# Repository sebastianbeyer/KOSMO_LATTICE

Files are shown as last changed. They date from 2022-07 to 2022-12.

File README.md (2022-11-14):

## KOSMO format adoption from Mutable Instruments Grids

Using the Schematic of Mutable Instruments and initial Kicad files by www.quinie.nl

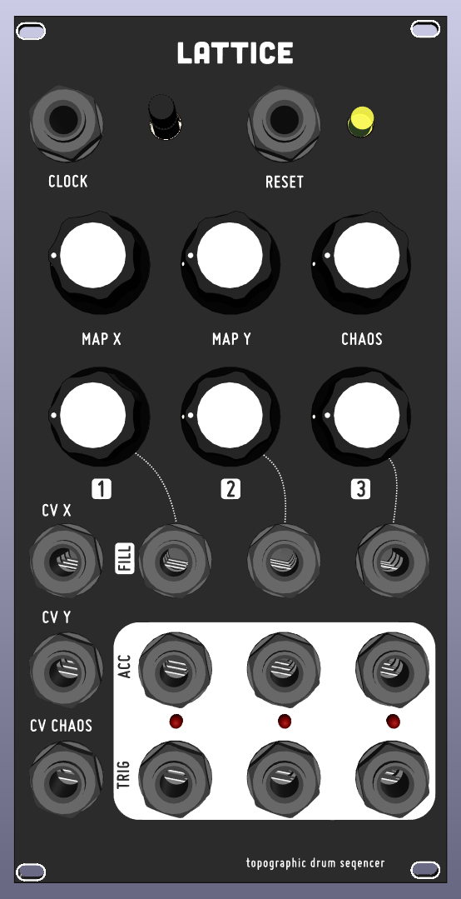
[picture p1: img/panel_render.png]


I had to fix the pot direction and the button but now it works!
Remember to adjust the LED resistors (`R37, R38, R39`) to the LEDs your are using!
For the firmware I have added the compiled firmware (`grids.hex`) and a script on how to upload it to your nano (`upload.sh`, you need to adjust the paths)

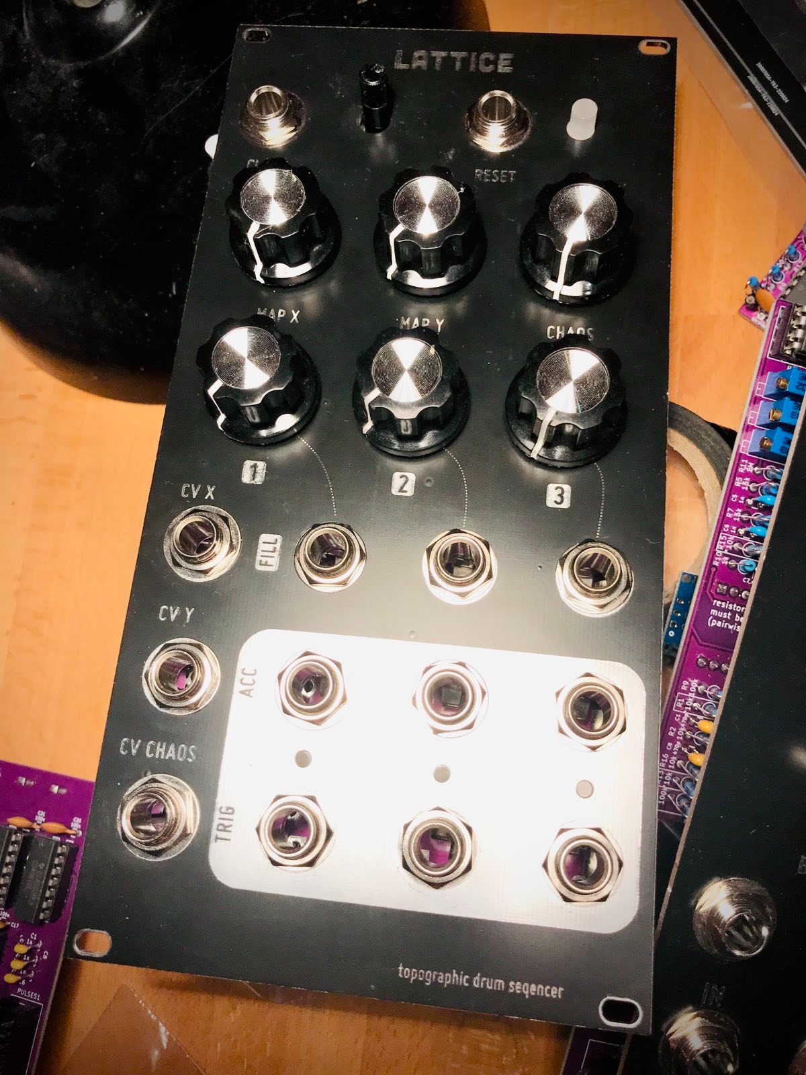
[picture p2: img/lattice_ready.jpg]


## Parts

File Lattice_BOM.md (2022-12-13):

# Lattice.kicad_sch BOM

Tue 13 Dec 2022 10:29:21 CET

Generated from schematic by Eeschema 6.0.8-f2edbf62ab~116~ubuntu22.04.1

**Component Count:** 107

| Refs | Qty | Component | Description | Vendor | SKU |
| ----- | --- | ---- | --- | ---- | ---- |
| A1 | 1 | Arduino_Nano_v2.x |  |  |  |
| C1, C2, C3, C4, C5, C6, C16 | 7 | 10nf |  |  |  |
| C7, C8, C10, C11, C12 | 5 | 100nf |  |  |  |
| C9, C14 | 2 | 10uf |  |  |  |
| C13, C15 | 2 | 0.47uf |  |  |  |
| CH1 | 1 | CH1 | Audio Jack, 2 Poles (Mono / TS), Switched T Pole (Normalling) | Tayda | A-1121 |
| CH1_AC1 | 1 | CH1_ACC | Audio Jack, 2 Poles (Mono / TS), Switched T Pole (Normalling) | Tayda | A-1121 |
| CH1_FILL1 | 1 | CV_CH1 | Audio Jack, 2 Poles (Mono / TS), Switched T Pole (Normalling) | Tayda | A-1121 |
| CH2 | 1 | CH2 | Audio Jack, 2 Poles (Mono / TS), Switched T Pole (Normalling) | Tayda | A-1121 |
| CH2_AC1 | 1 | CH2_ACC | Audio Jack, 2 Poles (Mono / TS), Switched T Pole (Normalling) | Tayda | A-1121 |
| CH2_FILL1 | 1 | CV_CH2 | Audio Jack, 2 Poles (Mono / TS), Switched T Pole (Normalling) | Tayda | A-1121 |
| CH3 | 1 | CH3 | Audio Jack, 2 Poles (Mono / TS), Switched T Pole (Normalling) | Tayda | A-1121 |
| CH3_AC1 | 1 | CH3_ACC | Audio Jack, 2 Poles (Mono / TS), Switched T Pole (Normalling) | Tayda | A-1121 |
| CH3_FILL1 | 1 | CV_CH3 | Audio Jack, 2 Poles (Mono / TS), Switched T Pole (Normalling) | Tayda | A-1121 |
| CLOCK1 | 1 | CV_CLOCK | Audio Jack, 2 Poles (Mono / TS), Switched T Pole (Normalling) | Tayda | A-1121 |
| D1, D5 | 2 | 1N4148 | Standard switching diode, DO-35 | Tayda | A-157 |
| D2 | 1 | CH1 | Light emitting diode |  |  |
| D3 | 1 | CH2 |  |  |  |
| D4 | 1 | CH3 |  |  |  |
| D6, D7 | 2 | 1N5817 | Schottky Barrier Rectifier Diode, DO-41 | Tayda | A-159 |
| H1, H2 | 2 | MountingHole |  |  |  |
| J1, J3 | 2 | Conn_01x10_Male | Generic connector, single row, 01x10, script generated (kicad-library-utils/schlib/autogen/connector/) |  |  |
| J2, J4 | 2 | Conn_01x10_Female | Generic connector, single row, 01x10, script generated (kicad-library-utils/schlib/autogen/connector/) |  |  |
| J5 | 1 | clock_out | KK254 Molex header | Tayda | A-804 |
| J6 | 1 | any trig | KK254 Molex header | Tayda | A-804 |
| J7 | 1 | midi in | KK254 Molex header | Tayda | A-805 |
| J8 | 1 | Synth_power_2x5 | Pin header 2.54 mm 2x5 | Tayda | A-2939 |
| P_CH1, P_CH2, P_CH3, P_RND1, P_TEMPO1, P_X1, P_Y1 | 7 | 10k |  |  |  |
| Q1, Q2 | 2 | 2N3904 |  |  |  |
| R1 | 1 | 2k |  |  |  |
| R2, R3, R4, R5, R6, R7, R8, R9, R10, R11, R12, R13, R16, R17, R19, R20, R21, R22, R23, R25, R26, R27, R28, R29, R34, R35, R36, R40, R41, R42 | 30 | 100k |  |  |  |
| R14, R15, R18, R24, R30, R31, R32, R33 | 8 | 1k |  |  |  |
| R37, R38, R39 | 3 | 2.2k |  |  |  |
| R43 | 1 | 10k |  |  |  |
| RESET1 | 1 | CV_RESET | Audio Jack, 2 Poles (Mono / TS), Switched T Pole (Normalling) | Tayda | A-1121 |
| RND1 | 1 | CV_RND | Audio Jack, 2 Poles (Mono / TS), Switched T Pole (Normalling) | Tayda | A-1121 |
| SW1 | 1 | PB6149-L-s |  |  |  |
| U1, U2, U3 | 3 | MCP6002_1 |  |  |  |
| U4 | 1 | 74HC595 |  |  |  |
| U5 | 1 | L7805 |  |  |  |
| U6 | 1 | LM4040LP-5 |  |  |  |
| X1 | 1 | CV_X | Audio Jack, 2 Poles (Mono / TS), Switched T Pole (Normalling) | Tayda | A-1121 |
| Y1 | 1 | CV_Y | Audio Jack, 2 Poles (Mono / TS), Switched T Pole (Normalling) | Tayda | A-1121 |

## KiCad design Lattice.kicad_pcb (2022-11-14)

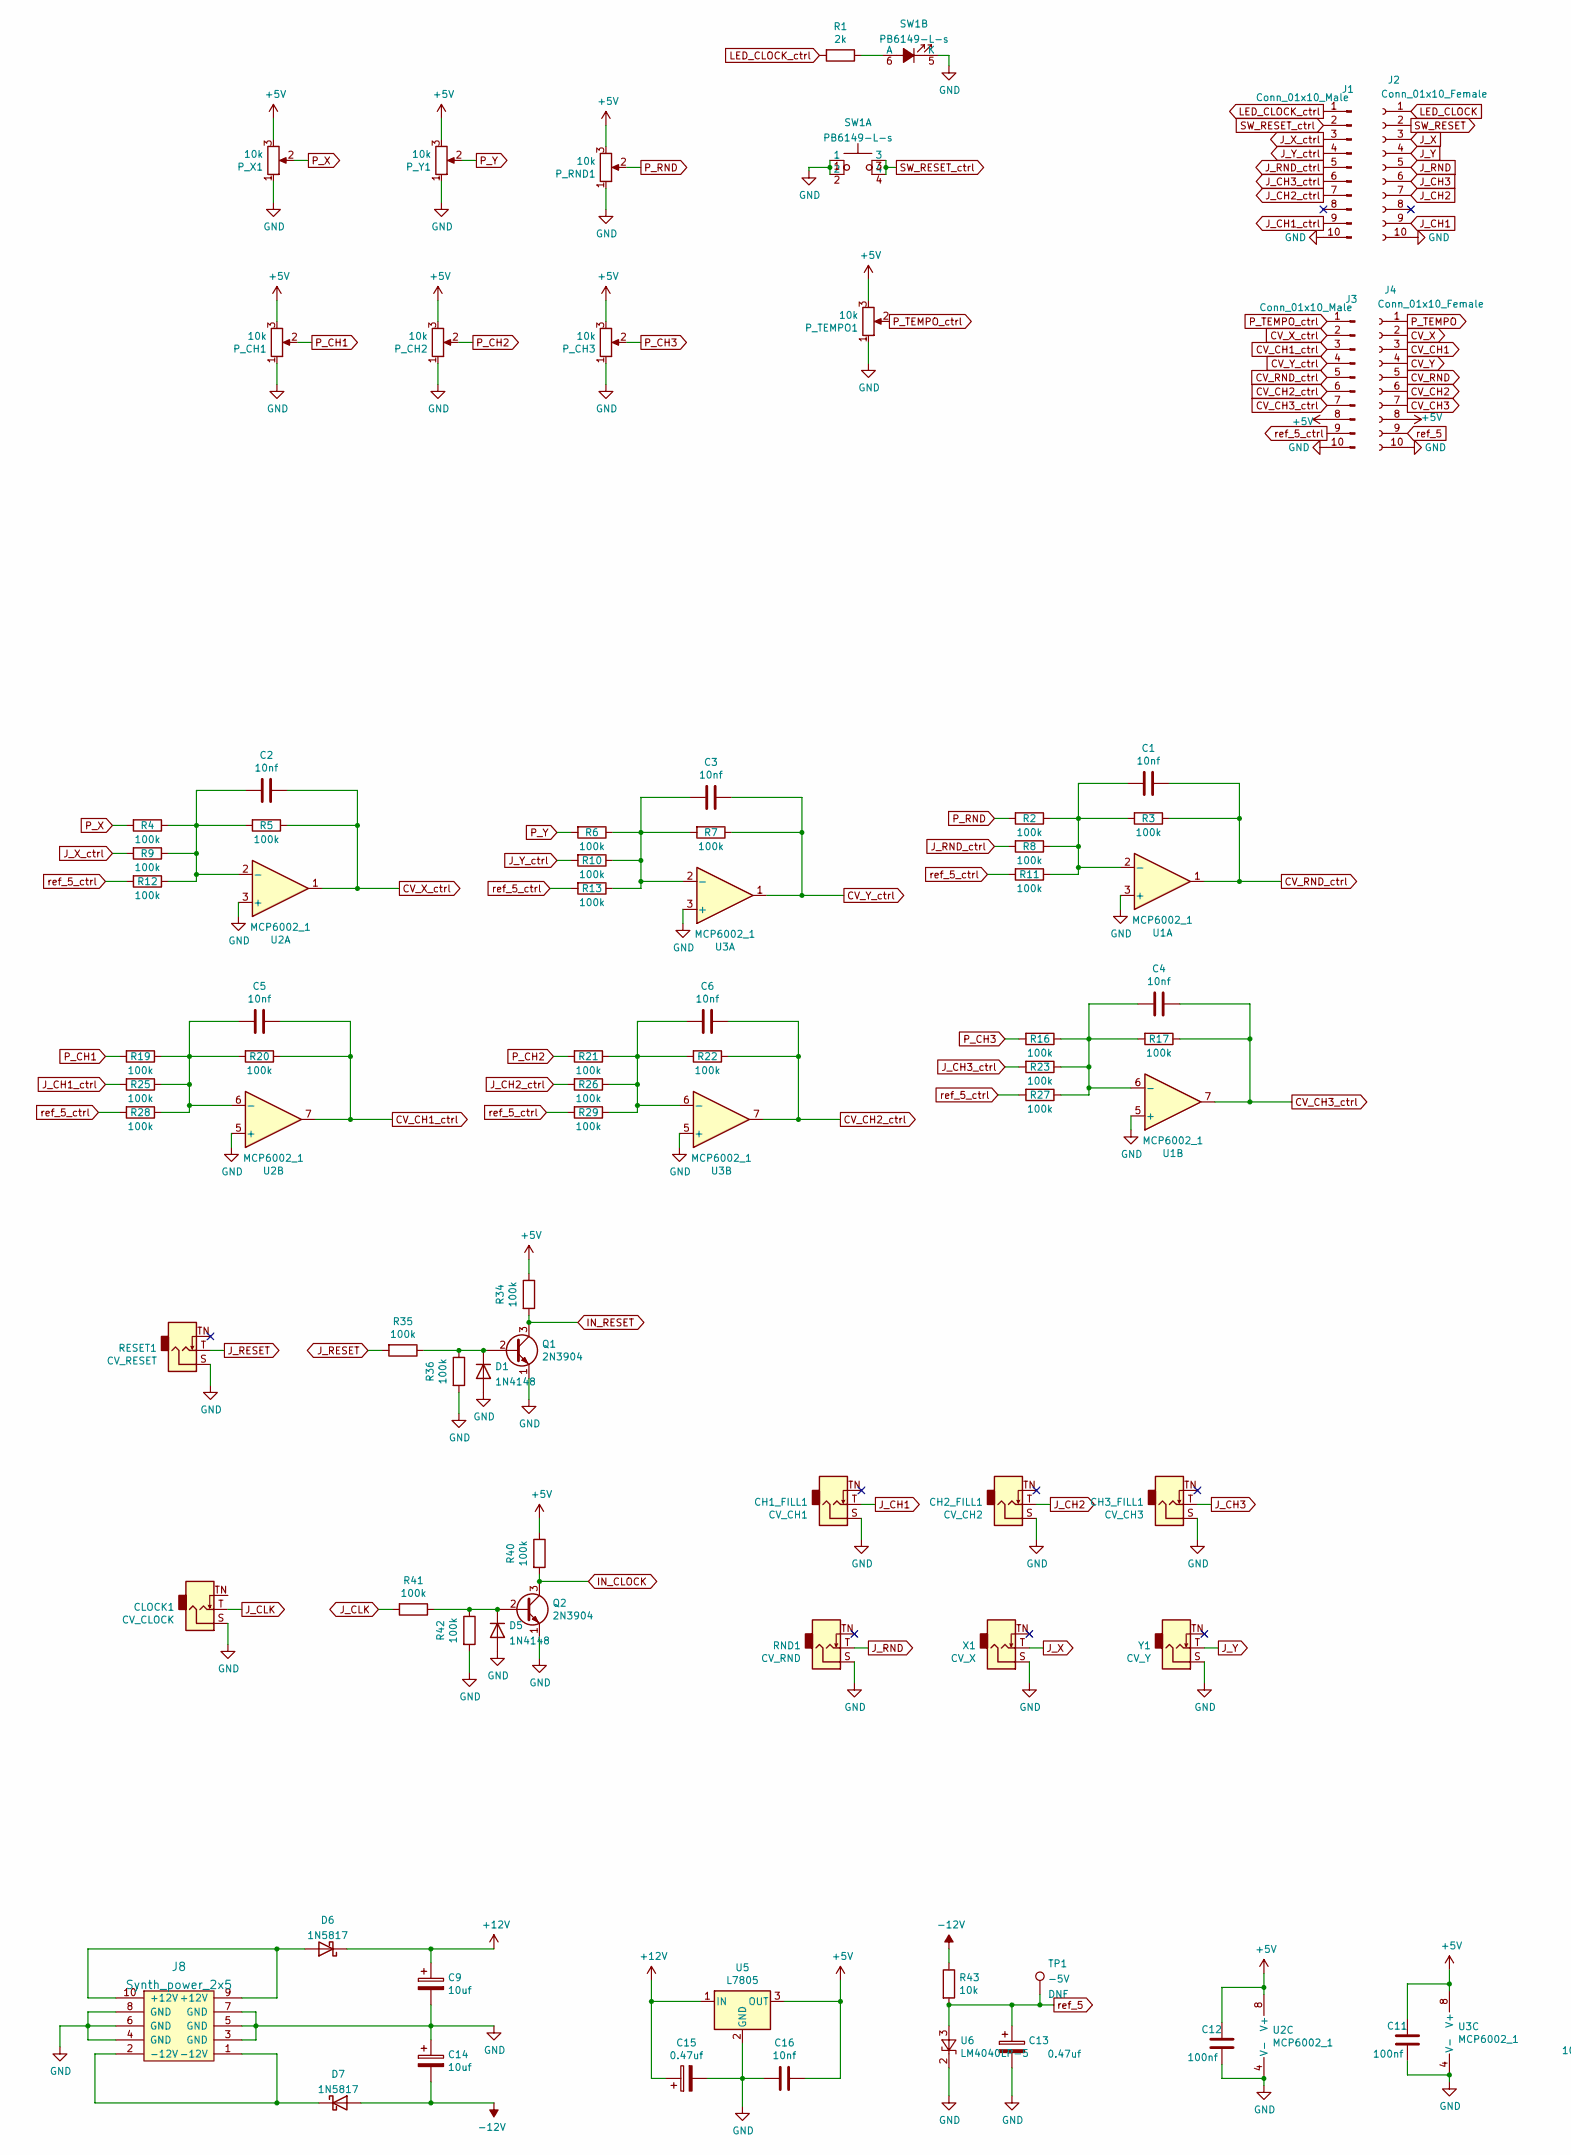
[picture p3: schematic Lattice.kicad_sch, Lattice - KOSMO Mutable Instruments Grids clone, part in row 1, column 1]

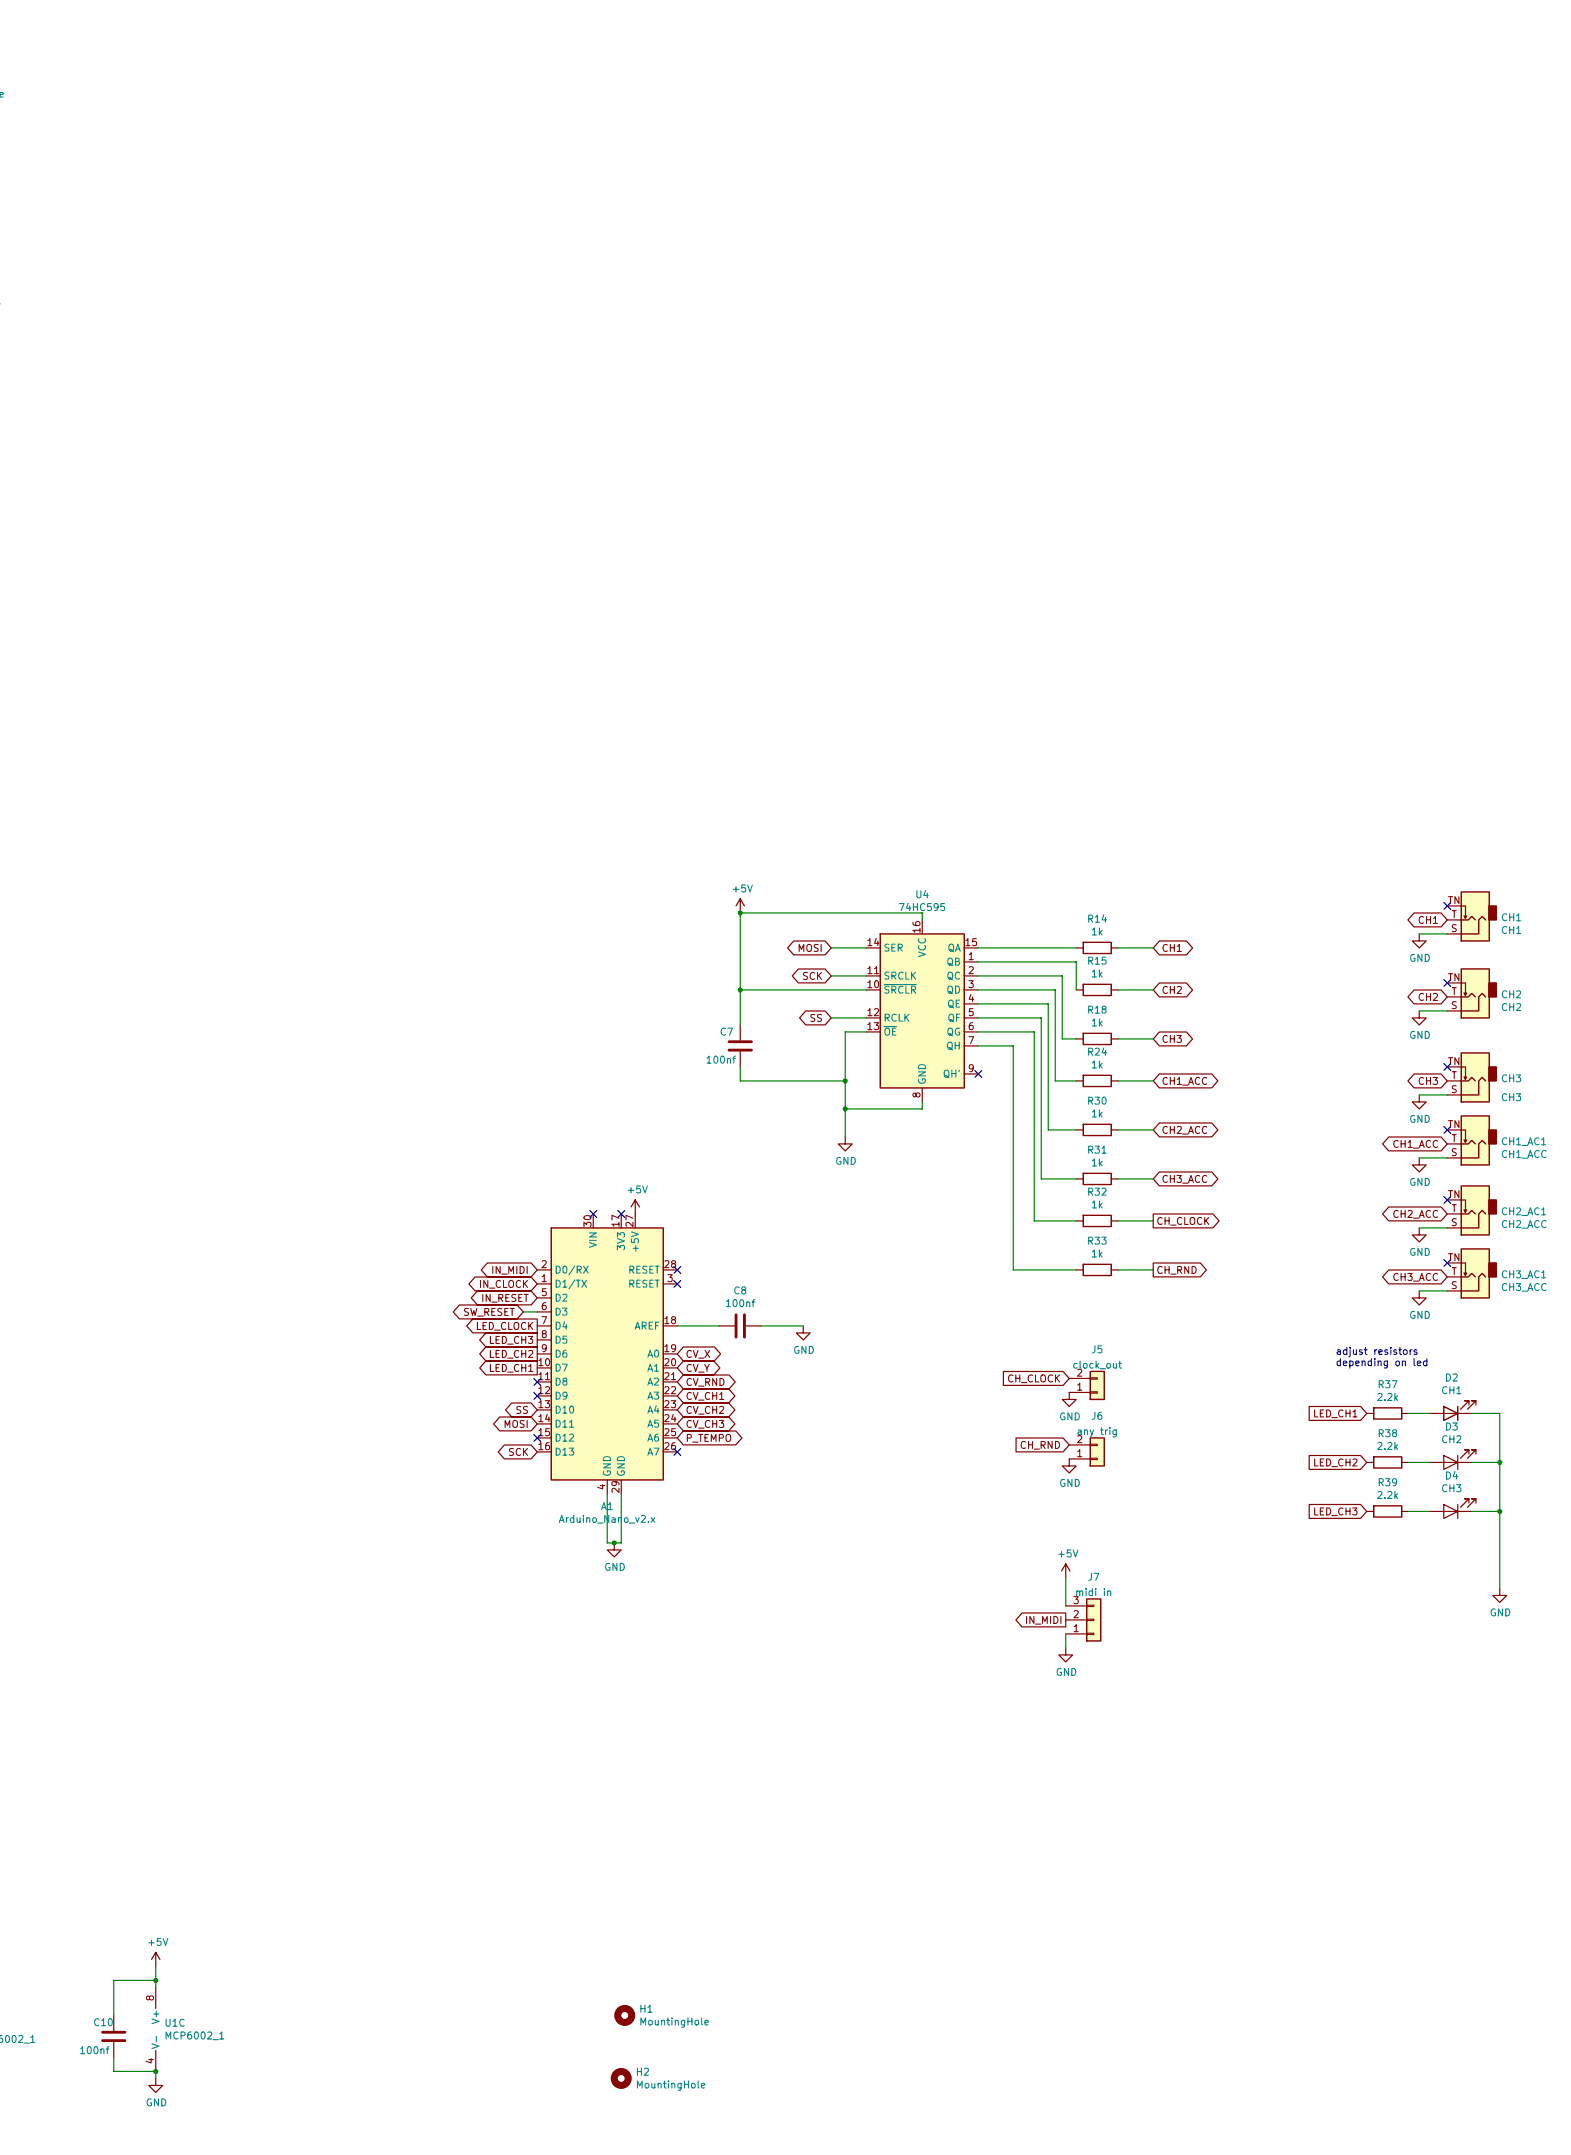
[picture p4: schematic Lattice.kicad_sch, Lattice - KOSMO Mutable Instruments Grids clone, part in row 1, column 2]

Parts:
A1: Arduino_Nano_v2.x; Arduino_Nano
C1, C2, C3, C4, C5, C6, C16: 10nf; C_Disc_D3.0mm_W1.6mm_P2.50mm
C7, C8, C10, C11, C12: 100nf; C_Disc_D3.0mm_W1.6mm_P2.50mm
C9, C14: 10uf; CP_Radial_horizontalflat_D5mm_P2.50mm_H10mm_south
C13, C15: 0.47uf; CP_Radial_horizontalflat_D5mm_P2.50mm_H10mm_south
CH1: CH1; Jack_6.35mm_PJ_629HAN
CH1_AC1: CH1_ACC; Jack_6.35mm_PJ_629HAN
CH1_FILL1: CV_CH1; Jack_6.35mm_PJ_629HAN
CH2: CH2; Jack_6.35mm_PJ_629HAN
CH2_AC1: CH2_ACC; Jack_6.35mm_PJ_629HAN
CH2_FILL1: CV_CH2; Jack_6.35mm_PJ_629HAN
CH3: CH3; Jack_6.35mm_PJ_629HAN
CH3_AC1: CH3_ACC; Jack_6.35mm_PJ_629HAN
CH3_FILL1: CV_CH3; Jack_6.35mm_PJ_629HAN
CLOCK1: CV_CLOCK; Jack_6.35mm_PJ_629HAN
D1, D5: 1N4148; D_DO-35_SOD27_P7.62mm_Horizontal
D2: CH1; LED_D3.0mm
D3: CH2; LED_D3.0mm
D4: CH3; LED_D3.0mm
D6, D7: 1N5817; D_DO-41_SOD81_P10.16mm_Horizontal
H1, H2: MountingHole; MountingHole_3.2mm_M3
J1, J3: Conn_01x10_Male; PinHeader_1x10_P2.54mm_Vertical
J2, J4: Conn_01x10_Female; PinSocket_1x10_P2.54mm_Vertical
J5: clock_out; Molex_KK-254_AE-6410-02A_1x02_P2.54mm_Vertical
J6: any trig; Molex_KK-254_AE-6410-02A_1x02_P2.54mm_Vertical
J7: midi in; Molex_KK-254_AE-6410-03A_1x03_P2.54mm_Vertical
J8: Synth_power_2x5; Power_Header
P_CH1, P_CH2, P_CH3: 10k; Potentiometer_Alpha_RD901F-40-00D_Single_Vertical_centered
P_RND1: 10k; Potentiometer_Alpha_RD901F-40-00D_Single_Vertical_centered
P_TEMPO1: 10k; Potentiometer_Alpha_RD901F-40-00D_Single_Vertical_centered
P_X1: 10k; Potentiometer_Alpha_RD901F-40-00D_Single_Vertical_centered
P_Y1: 10k; Potentiometer_Alpha_RD901F-40-00D_Single_Vertical_centered
Q1, Q2: 2N3904; TO-92_Inline_Wide
R1: 2k; R_Axial_DIN0207_L6.3mm_D2.5mm_P10.16mm_Horizontal
R2, R3, R4, R5, R6, R7, R8, R9, R10, R11, R12, R13, R16, R17, R19, R20, R21, R22, R23, R25, R26, R27, R28, R29, R34, R35, R36, R40, R41, R42: 100k; R_Axial_DIN0207_L6.3mm_D2.5mm_P10.16mm_Horizontal
R14, R15, R18, R24, R30, R31, R32, R33: 1k; R_Axial_DIN0207_L6.3mm_D2.5mm_P10.16mm_Horizontal
R37, R38, R39: 2.2k; R_Axial_DIN0207_L6.3mm_D2.5mm_P10.16mm_Horizontal
R43: 10k; R_Axial_DIN0207_L6.3mm_D2.5mm_P10.16mm_Horizontal
RESET1: CV_RESET; Jack_6.35mm_PJ_629HAN
RND1: CV_RND; Jack_6.35mm_PJ_629HAN
SW1: PB6149-L-s; HIGHLY_PB6149L
TP1: -5V; TestPoint_THTPad_D1.5mm_Drill0.7mm
U1, U2, U3: MCP6002_1; DIP-8_W7.62mm_Socket_LongPads
U4: 74HC595; DIP-16_W7.62mm_Socket_LongPads
U5: L7805; TO-220-3_Horizontal_TabDown
U6: LM4040LP-5; TO-92_Inline_Wide
X1: CV_X; Jack_6.35mm_PJ_629HAN
Y1: CV_Y; Jack_6.35mm_PJ_629HAN

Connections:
+5V: A1.27 (+5V), C7.1, C10.1, C11.1, C12.1, C16.1, J3.8, J4.8, J7.3, P_CH1.3, P_CH2.3, P_CH3.3, P_RND1.3, P_TEMPO1.3, P_X1.3, P_Y1.3, R34.1, R40.1, U1.8 (V+), U2.8 (V+), U3.8 (V+), U4.10 (~SRCLR), U4.16 (VCC), U5.3 (OUT)
+12V: C9.1, C15.1, D6.1 (K), U5.1 (IN)
-12V: C14.2, D7.2 (A), R43.1
CH1: CH1.T, R14.1
CH1_ACC: CH1_AC1.T, R24.1
CH2: CH2.T, R15.1
CH2_ACC: CH2_AC1.T, R30.1
CH3: CH3.T, R18.1
CH3_ACC: CH3_AC1.T, R31.1
CH_CLOCK: J5.2, R32.1
CH_RND: J6.2, R33.1
CV_CH1: A1.22 (A3), J4.3
CV_CH1_ctrl: C5.1, J3.3, R20.1, U2.7
CV_CH2: A1.23 (A4), J4.6
CV_CH2_ctrl: C6.1, J3.6, R22.1, U3.7
CV_CH3: A1.24 (A5), J4.7
CV_CH3_ctrl: C4.1, J3.7, R17.1, U1.7
CV_RND: A1.21 (A2), J4.5
CV_RND_ctrl: C1.1, J3.5, R3.1, U1.1
CV_X: A1.19 (A0), J4.2
CV_X_ctrl: C2.1, J3.2, R5.1, U2.1
CV_Y: A1.20 (A1), J4.4
CV_Y_ctrl: C3.1, J3.4, R7.1, U3.1
GND: A1.4 (GND), A1.29 (GND), C7.2, C8.1, C9.2, C10.2, C11.2, C12.2, C13.2, C14.1, C15.2, C16.2, CH1.S, CH1_AC1.S, CH1_FILL1.S, CH2.S, CH2_AC1.S, CH2_FILL1.S, CH3.S, CH3_AC1.S, CH3_FILL1.S, CLOCK1.S, D1.2 (A), D2.1 (K), D3.1 (K), D4.1 (K), D5.2 (A), J1.10, J2.10, J3.10, J4.10, J5.1, J6.1, J7.1, J8.3 (GND), J8.4 (GND), J8.5 (GND), J8.6 (GND), J8.7 (GND), J8.8 (GND), P_CH1.1, P_CH2.1, P_CH3.1, P_RND1.1, P_TEMPO1.1, P_X1.1, P_Y1.1, Q1.1 (E), Q2.1 (E), R36.2, R42.2, RESET1.S, RND1.S, SW1.1, SW1.2, SW1.5 (K), U1.3 (+), U1.4 (V-), U1.5 (+), U2.3 (+), U2.4 (V-), U2.5 (+), U3.3 (+), U3.4 (V-), U3.5 (+), U4.8 (GND), U4.13 (~OE), U5.2 (GND), U6.2 (K), X1.S, Y1.S; also elsewhere on the board
IN_CLOCK: A1.1 (D1/TX), Q2.3 (C), R40.2
IN_MIDI: A1.2 (D0/RX), J7.2
IN_RESET: A1.5 (D2), Q1.3 (C), R34.2
J_CH1: CH1_FILL1.T, J2.9
J_CH1_ctrl: J1.9, R25.2
J_CH2: CH2_FILL1.T, J2.7
J_CH2_ctrl: J1.7, R26.2
J_CH3: CH3_FILL1.T, J2.6
J_CH3_ctrl: J1.6, R23.2
J_CLK: CLOCK1.T, R41.2
J_RESET: R35.2, RESET1.T
J_RND: J2.5, RND1.T
J_RND_ctrl: J1.5, R8.2
J_X: J2.3, X1.T
J_X_ctrl: J1.3, R9.2
J_Y: J2.4, Y1.T
J_Y_ctrl: J1.4, R10.2
LED_CH1: A1.10 (D7), R37.2
LED_CH2: A1.9 (D6), R38.2
LED_CH3: A1.8 (D5), R39.2
LED_CLOCK: A1.7 (D4), J2.1
LED_CLOCK_ctrl: J1.1, R1.2
MOSI: A1.14 (D11), U4.14 (SER)
unnamed: A1.18 (AREF), C8.2
unnamed: C1.2, R2.1, R3.2, R8.1, R11.1, U1.2 (-)
unnamed: C2.2, R4.1, R5.2, R9.1, R12.1, U2.2 (-)
unnamed: C3.2, R6.1, R7.2, R10.1, R13.1, U3.2 (-)
unnamed: C4.2, R16.1, R17.2, R23.1, R27.1, U1.6 (-)
unnamed: C5.2, R19.1, R20.2, R25.1, R28.1, U2.6 (-)
unnamed: C6.2, R21.1, R22.2, R26.1, R29.1, U3.6 (-)
unnamed: D1.1 (K), Q1.2 (B), R35.1, R36.1
unnamed: D2.2 (A), R37.1
unnamed: D3.2 (A), R38.1
unnamed: D4.2 (A), R39.1
unnamed: D5.1 (K), Q2.2 (B), R41.1, R42.1
unnamed: D6.2 (A), J8.9 (+12V), J8.10 (+12V)
unnamed: D7.1 (K), J8.1 (-12V), J8.2 (-12V)
unnamed: R1.1, SW1.6 (A)
unnamed: R14.2, U4.15 (QA)
unnamed: R15.2, U4.1 (QB)
unnamed: R18.2, U4.2 (QC)
unnamed: R24.2, U4.3 (QD)
unnamed: R30.2, U4.4 (QE)
unnamed: R31.2, U4.5 (QF)
unnamed: R32.2, U4.6 (QG)
unnamed: R33.2, U4.7 (QH)
P_CH1: P_CH1.2, R19.2
P_CH2: P_CH2.2, R21.2
P_CH3: P_CH3.2, R16.2
P_RND: P_RND1.2, R2.2
P_TEMPO: A1.25 (A6), J4.1
P_TEMPO_ctrl: J3.1, P_TEMPO1.2
P_X: P_X1.2, R4.2
P_Y: P_Y1.2, R6.2
SCK: A1.16 (D13), U4.11 (SRCLK)
SS: A1.13 (D10), U4.12 (RCLK)
SW_RESET: A1.6 (D3), J2.2
SW_RESET_ctrl: J1.2, SW1.3, SW1.4
ref_5: C13.1, J4.9, R43.2, TP1.1, U6.3 (A)
ref_5_ctrl: J3.9, R11.2, R12.2, R13.2, R27.2, R28.2, R29.2

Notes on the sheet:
adjust resistors depending on led

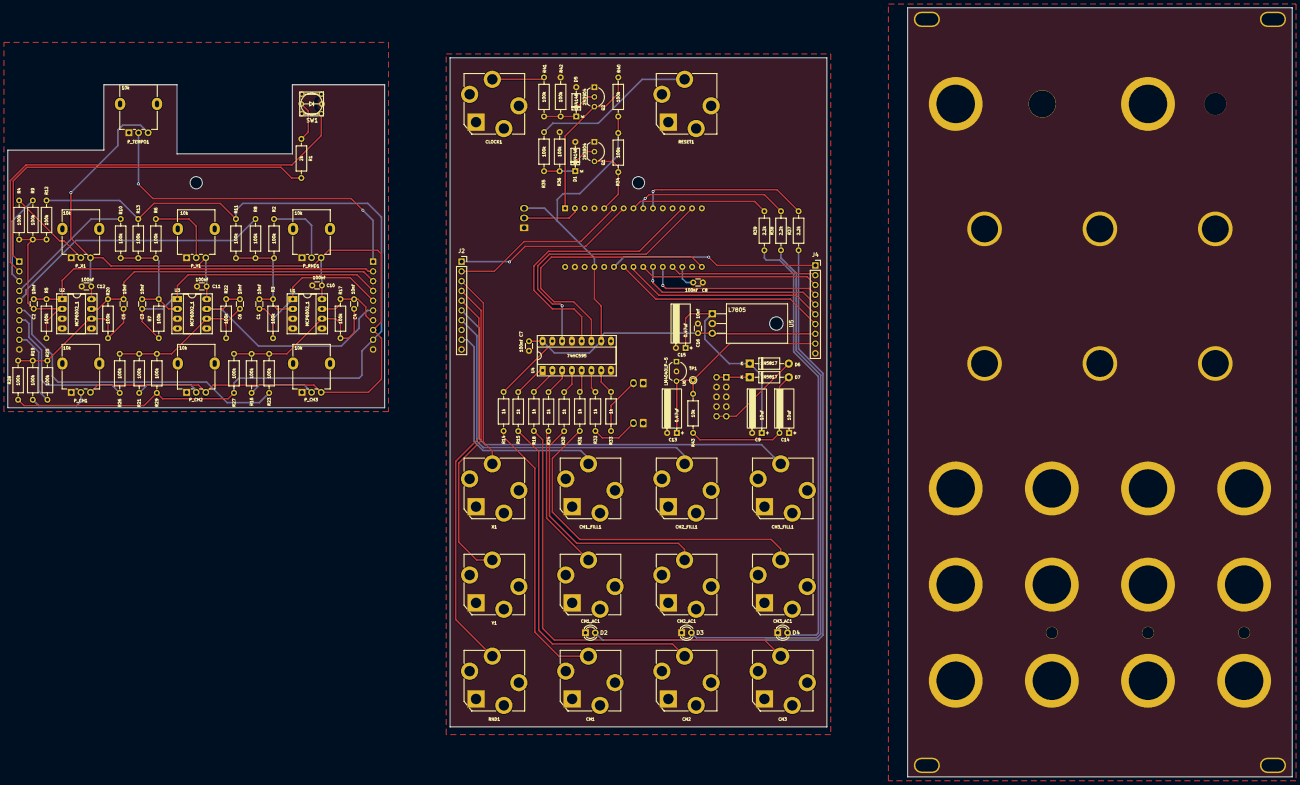
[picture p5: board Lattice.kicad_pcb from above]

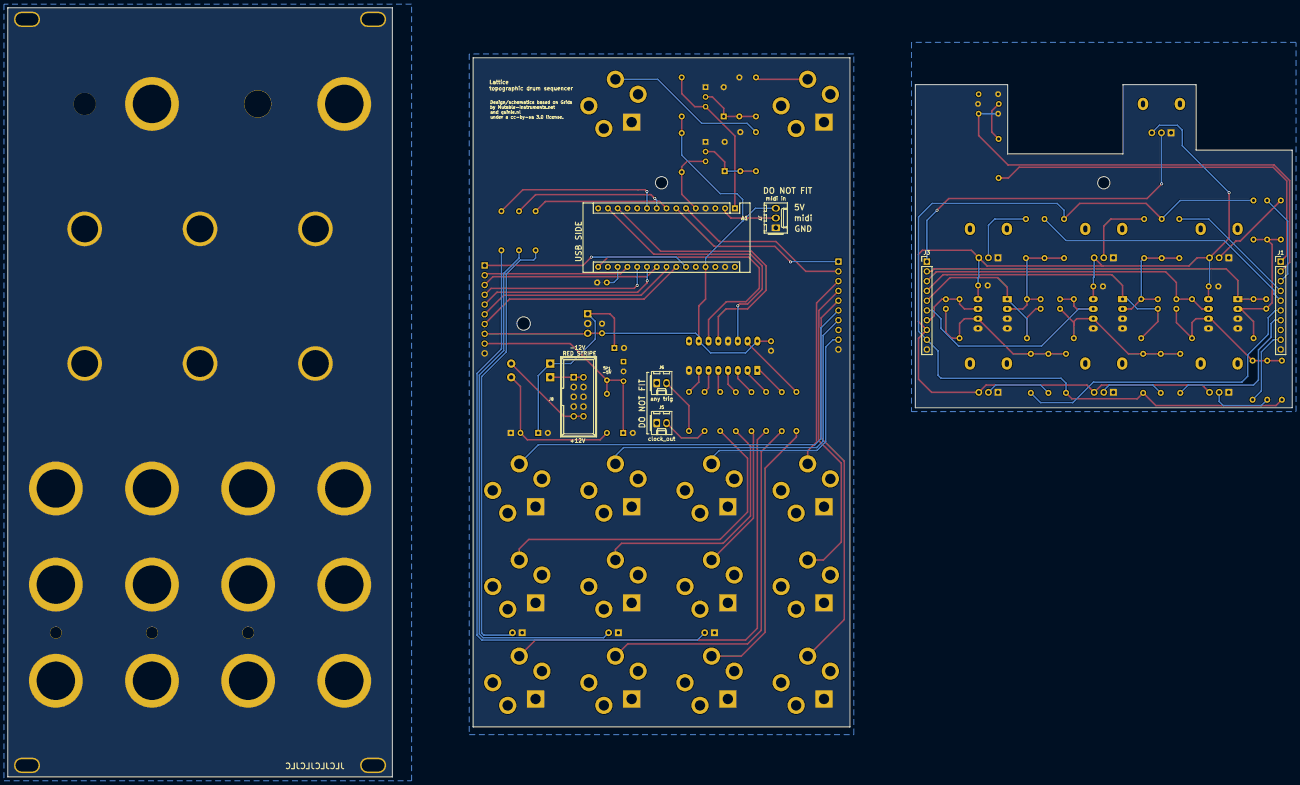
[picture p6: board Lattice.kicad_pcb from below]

Board: 2 copper layers, 334.0 x 200.0 mm, 109 parts (7 on the bottom side), 84 nets.

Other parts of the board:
H25: led; Kosmo_HIGHLY_PB6149L

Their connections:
GND: H25.1; also elsewhere on the board

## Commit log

2022-09-12 fix pot direction
    [Lattice.kicad_pcb, Lattice.kicad_sch]
2022-11-14 fix button
    [Lattice.kicad_pcb, Lattice.kicad_sch]
2022-11-14 add note on LED resistors
2022-12-13 add bom
2022-12-13 rename bom

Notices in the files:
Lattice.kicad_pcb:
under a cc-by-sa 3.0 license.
